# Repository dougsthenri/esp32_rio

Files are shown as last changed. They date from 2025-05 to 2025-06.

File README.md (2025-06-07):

# ESP32 Remote I/O

A low-cost industrial remote input/output device based on the ESP32-S3 SoC from Espressif.

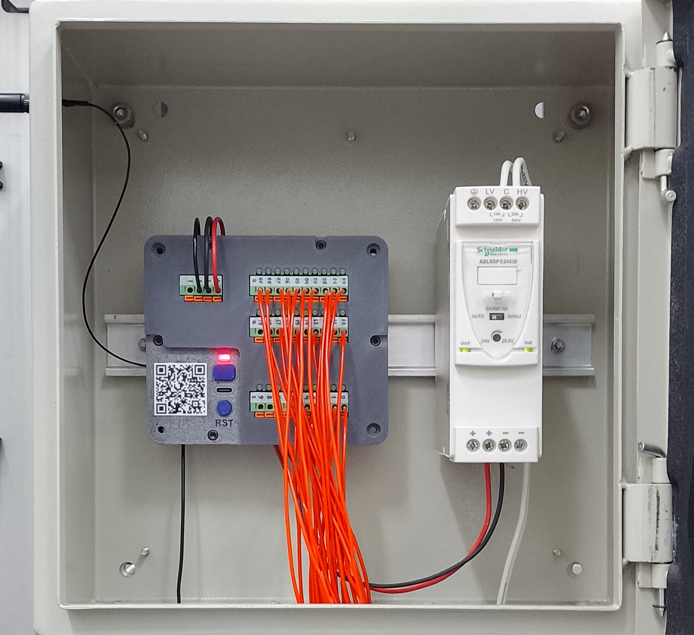
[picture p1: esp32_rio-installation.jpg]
ESP32 RIO installation ESP32 RIO installed inside panel


## Features

* **WiFi Connectivity:** Connects to an existing WiFi network using configuration read from non-volatile storage. External antenna.
* **Digital Inputs (DI):** Ten 24 V digital, sink type, inputs.
* **Digital Outputs (DQ):** Twenty 24 V digital, sink type, outputs.
* **Output Enable (OE) Button:** A push button to globally enable/disable digital outputs.
* **Status LED:** Steady on when digital outputs are enabled. Blinks Morse code for the letter W when disconnected from WiFi network.
* **USB Console:** A command-line interface over USB Serial/JTAG for runtime configuration (e.g., WiFi setup) and debugging.
* **Reset Button:** For manually restarting the board.
* **Power Input:** 24 V, 267 mA (max.).

---
*For any issues or contributions, please refer to the project's [GitHub repository](https://github.com/dougsthenri/esp32_rio.git).*

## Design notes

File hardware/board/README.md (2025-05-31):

# esp32_rio
PCB project for a low-cost industrial remote I/O device based on the ESP32-S3 SoC from Espressif.
Proudly made using KiCad 9.0.

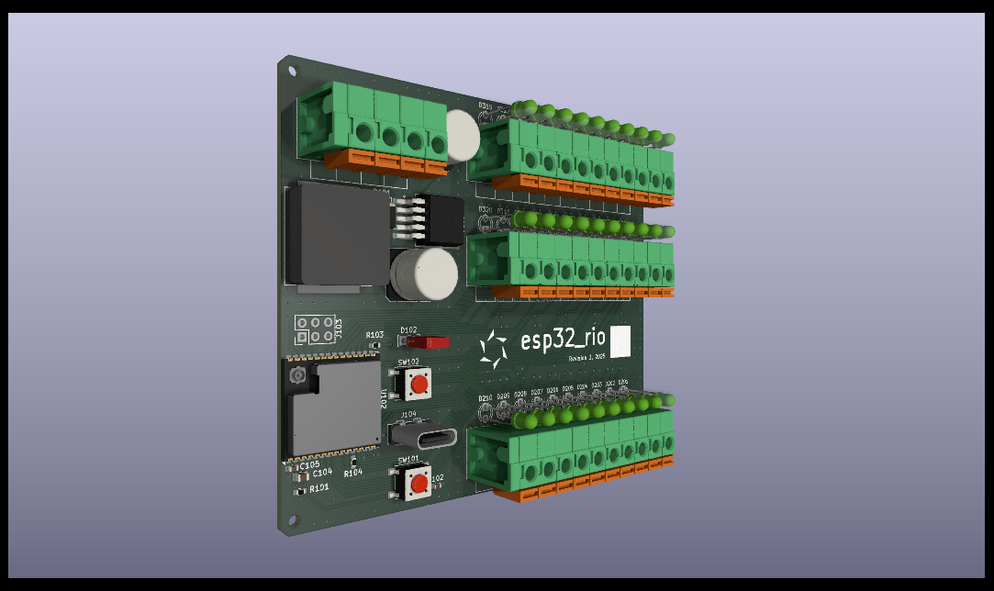
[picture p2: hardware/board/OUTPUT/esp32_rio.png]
PCB rendering


---
*For any issues or contributions, please refer to the project's [GitHub repository](https://github.com/dougsthenri/esp32_rio.git).*

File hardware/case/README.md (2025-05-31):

# ESP32 Remote I/O Case
A 3D-printable plastic case for the ESP32 RIO board.

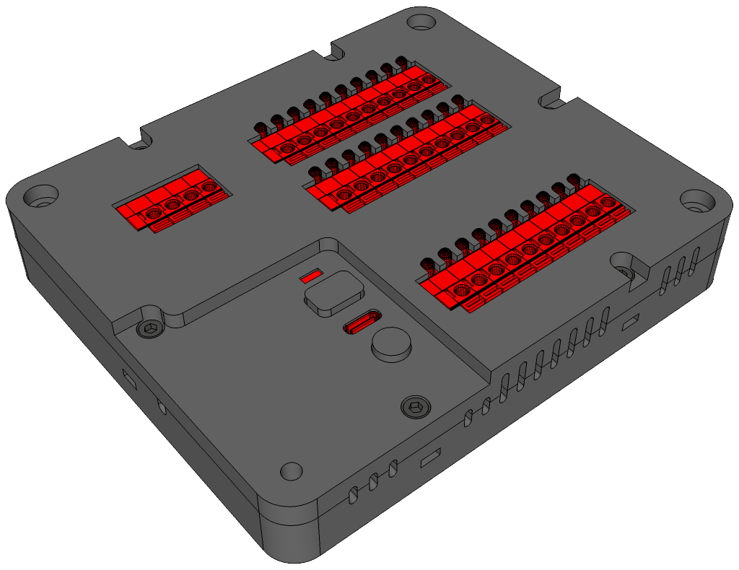
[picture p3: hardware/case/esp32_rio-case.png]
ESP32 RIO case ESP32 RIO case render


The encased board can be mounted on a 35 mm DIN rail by attaching two 43 mm mounting brackets on its back. Alternatively it can be directly mounted to a wall by using four 4x25 mm screws.
Refer to the `esp32_rio-case.skp` file for the complete case assembly.

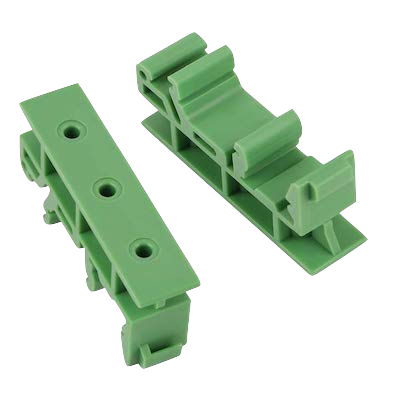
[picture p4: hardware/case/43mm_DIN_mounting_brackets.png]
43 mm DIN mounting brackets


---
*For any issues or contributions, please refer to the project's [GitHub repository](https://github.com/dougsthenri/esp32_rio.git).*

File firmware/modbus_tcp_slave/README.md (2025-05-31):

# ESP32 Remote I/O Modbus TCP Slave

## Project Overview

This project implements a Modbus TCP slave firmware for the ESP32 RIO board. The board's digital inputs (DI0-9) are exposed as Modbus discrete inputs and its digital outputs (DQ00-19) as Modbus coils. The output enable function is also controllable by means of a Modbus coil.

## 1. Setup, Compile, and Flash Instructions (ESP-IDF)

This project is built using the Espressif IoT Development Framework (ESP-IDF), version 5.4.1. Follow these steps to set up your development environment, compile the firmware, and flash it onto the ESP32 RIO board.

### 1.1. Prerequisites

* **ESP-IDF Installation:** If you haven't already, follow the official ESP-IDF Getting Started Guide for your operating system. This guide will walk you through installing the necessary tools, including Python, Git, and the ESP-IDF toolchain.
    * [ESP-IDF Get Started Guide](https://docs.espressif.com/projects/esp-idf/en/latest/esp32s3/get-started/index.html)
* **Python:** Ensure Python 3.7 or higher is installed.
* **Git:** Ensure Git is installed for cloning the repository.

### 1.2. Getting the Code

1.  **Clone the repository:**
    ```bash
    git clone [https://github.com/dougsthenri/esp32_rio.git](https://github.com/dougsthenri/esp32_rio.git)
    cd esp32_rio/firmware/modbus_tcp_slave
    ```

### 1.3. Environment Setup

Before building, you need to set up the ESP-IDF environment variables. If you followed the official guide, you should have a script to do this.

* **Linux/macOS:**
    ```bash
    . $HOME/esp/esp-idf/export.sh
    ```
    (Adjust path if your ESP-IDF installation is in a different location).
* **Windows (ESP-IDF Command Prompt):** Use the `ESP-IDF Command Prompt` shortcut installed by the ESP-IDF installer.

### 1.4. Configuration

1.  **Open the project configuration menu:**
    ```bash
    idf.py menuconfig
    ```
2.  **Navigate and configure:** Make any adjustments you deem necessary to the provided configuration.
3.  **Save and exit.**

### 1.5. Build the Project

1.  **Build the application:**
    ```bash
    idf.py build
    ```
    This command will compile all source files and generate the necessary firmware binaries.

### 1.6. Flash the Firmware

1.  **Connect the ESP32 RIO board:** Connect the ESP32 RIO board to your computer via the USB-C port (USB Serial/JTAG).
2.  **Flash the firmware:**
    ```bash
    idf.py -p YOUR_SERIAL_PORT flash
    ```
    Replace `YOUR_SERIAL_PORT` with the actual serial port of the board (e.g., `/dev/ttyUSB0` on Linux, `COMx` on Windows).
    This command will erase the flash and write the new firmware.

### 1.7. Monitor Serial Output

After flashing, you can monitor the serial output for logs and debugging information:
```bash
idf.py -p YOUR_SERIAL_PORT monitor
```
Press `Ctrl+]` to exit the monitor.

## 2. Modbus Objects

The firmware implements various Modbus objects (coils, discrete inputs) that map directly to the ESP32 RIO board's GPIOs and internal functionalities. The Modbus TCP port is **502**. The Modbus slave address is **1**.

### 2.1. Modbus Register Map

| Modbus Type | Address Range | Assignment / Description |
| :--- | :--- | :--- |
| **Coils** | `0x0000` | `DQ00` (Digital Output 0) |
| | `0x0001` | `DQ01` (Digital Output 1) |
| | ... | ... |
| | `0x0009` | `DQ09` (Digital Output 9) |
| | `0x0010` (`16`) | `DQ10` (Digital Output 10) |
| | ... | ... |
| | `0x0019` (`25`) | `DQ19` (Digital Output 19) |
| | `0x001F` (`31`) | `Output Enable (OE)`: Controls the global enable/disable state for all digital outputs. `1` = enabled, `0` = disabled. This coil also reflects the state set by the physical OE toggle button. |
| **Discrete Inputs** | `0x0000` | `DI0` (Digital Input 0) |
| | `0x0001` | `DI1` (Digital Input 1) |
| | ... | ... |
| | `0x0009` | `DI9` (Digital Input 9) |

*Note: Holding Registers and Input Registers are currently not implemented in this version.*

## 3. USB Console Communication

You can interact with the board using a standard serial terminal application connected to the USB-C port. This provides a command-line interface for configuring and monitoring the Modbus slave operation.

### 3.1. How to Connect

1.  **Connect USB-C:** Plug the ESP32 RIO board into your computer using the USB-C cable.
2.  **Identify Serial Port:** The board will enumerate as a serial port. Identify its name (e.g., `/dev/ttyUSB0` on Linux, `COMx` on Windows, `/dev/cu.usbserial-xxxx` on macOS).
3.  **Open Terminal:** Use any raw serial terminal application (e.g., Arduino serial monitor, PuTTY, Termite, picocom or even `idf.py monitor`). Enable the terminal's local echo to see the commands you typed. There's no firmware support for line editing.
4.  **Configure Serial Settings:**
    * **Baud Rate:** Not strictly applicable for USB Serial, but many terminals will default to 115200. Setting it to a common speed like 115200 or 9600 usually works, as the communication is USB-native, not UART.
    * **Data Bits:** 8
    * **Stop Bits:** 1
    * **Parity:** None
    * **Flow Control:** None
5.  **Start Session:** Open the connection. You may see some log messages.

### 3.2. Console Commands

Once connected to the USB console, you can type commands and press Enter to execute them. There must be no space before or after the full command text and only a single space before each command argument. Enclose with double quotes (“) any text argument containing spaces. Double quotes and literal backslashes (\\) must be preceded by backslashes when inside quoted text.

| Command | Description |
| :--- | :--- |
| `help` | Displays a list of all recognized commands and their brief descriptions. |
| `wifi-status` | Shows the current WiFi connection status of the TCP Modbus slave. If connected, it will display the SSID, IP address, and other relevant network information. |
| `wifi-config SSID PASSWORD` | Configures the WiFi network credentials (SSID and password) for the TCP Modbus slave to connect to. Both arguments are mandatory and non-empty. After a successful configuration, the device will save the credentials to NVS and reboot to connect. |

**Example Usage:**

```
wifi-config "My Wifi Network" MySecurePassword
[wifi-config] Configuration successful. Rebooting...
```
```
wifi-status
[wifi-status] Connected to "My Wifi Network":
  IP Address: 192.168.1.100
  Subnet Mask: 255.255.255.0
  Gateway: 192.168.1.1
```

---
*For any issues or contributions, please refer to the project's [GitHub repository](https://github.com/dougsthenri/esp32_rio.git).*

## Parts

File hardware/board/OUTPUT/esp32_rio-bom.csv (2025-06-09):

Reference | Value | Qty | DNP | Part# | Tolerance | Voltage
C101 | 100µ | 1 |  | EEHZC1H101P |  | 50V
C102 | 1µ | 1 |  | CL10B105KQ8NNNC |  | 6.3V
C103 | 680µ | 1 |  | EEEFK1V331P |  | 35V
C104 | 22µ | 1 |  | GRM21BZ70J226ME44L |  | 6.3V
C105,C201,C202,C203,C204,C205 | 100n | 6 |  | CC0603JRX7R9BB104
C206 | 10µ | 1 |  | CL21B106KAYQNNE
D101 | SS26T3G | 1 |  | SS26T3G
D102 | Red | 1 |  | L-403SRD
D201,D202,D203,D204,D205,D206,D207,D208,D209,D210,D301,D302,D303,D304,D305,D306,D307,D308,D309,D310,D311,D312,D313,D314,D315,D316,D317,D318,D319,D320 | Green | 30 |  | 204-10SYGD/S530-E2-L
J101 | 24V_Power | 1 |  | KF142V-5.08-4P
J103 | External_Programmer | 1 | DNP
J104 | Programming_Port | 1 |  | GT-USB-7035D
J201 | Digital_Input | 1 |  | KF142V-5.08-10P
J301 | Digital_Output_Bank_0 | 1 |  | KF142V-5.08-10P
J302 | Digital_Output_Bank_1 | 1 |  | KF142V-5.08-10P
L101 | 68µ | 1 |  | IHLP6767GZER680M11
Q101,Q201,Q202,Q203,Q204,Q205,Q206,Q207,Q208,Q209,Q210,Q321,Q322,Q323,Q324,Q325,Q326,Q327,Q328,Q329,Q330,Q331,Q332,Q333,Q334,Q335,Q336,Q337,Q338,Q339,Q340 | BSS138 | 31 |  | BSS138-7-F
Q301,Q302,Q303,Q304,Q305,Q306,Q307,Q308,Q309,Q310,Q311,Q312,Q313,Q314,Q315,Q316,Q317,Q318,Q319,Q320 | IRLML6344 | 20 |  | IRLML6344TRPBF
R101,R102,R103 | 10k | 3 |  | RC0603FR-0710KL
R104 | 100 | 1 |  | AC0603FR-07100RL
R105,R272,R273,R274,R275,R276,R277,R278,R279,R280,R281,R301,R302,R303,R304,R305,R306,R307,R308,R309,R310,R311,R312,R313,R314,R315,R316,R317,R318,R319,R320 | 68 | 31 |  | RC0603FR-0768RL
R106,R107 | 5.1k | 2 |  | RC0603FR-075K1L | 1%
R201,R202,R203,R204,R205,R206,R207,R208,R209,R210,R211,R212,R213,R214,R215,R216,R241,R242,R243,R244,R245,R246,R247,R248,R249,R250,R251,R252,R253,R254,R255,R256,R263,R264,R265,R267,R268,R269,R270,R271 | 1M | 40 |  | RC0603FR-071ML | 1%
R217,R218,R219,R220,R237,R238,R239,R240,R261,R262 | 649k | 10 |  | RC0603FR-07649KL | 1%
R221,R222,R223,R224,R233,R234,R235,R236,R259,R260 | 1.2k | 10 |  | RC0603FR-071K2L | 1%
R225,R226,R227,R228,R229,R230,R231,R232,R257,R258 | 10k | 10 |  | RC0603FR-0710KL | 1%
R266 | 330 | 1 |  | RC0603FR-07330RL
SW101 | Reset | 1 |  | PTS645SH95SMTR92LFS
SW102 | Toggle_Outputs | 1 |  | PTS645SH95SMTR92LFS
U101 | LM2596S-3.3 | 1 |  | LM2596SX-3.3/NOPB
U102 | ESP32-S3-WROOM-1U | 1 |  | ESP32-S3-WROOM-1U-N16R2
U201,U202,U203,U204,U205 | TLV3202AID | 5 |  | TLV3202AIDR
U206 | TL431 | 1 |  | ZTL431AFTA

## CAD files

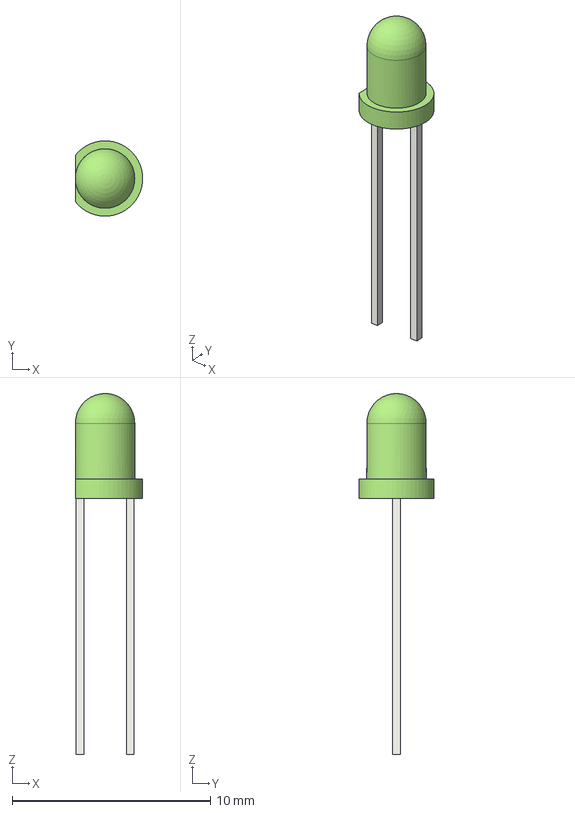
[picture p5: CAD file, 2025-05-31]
hardware/board/esp32_rio-3dmodels/LED_D3.0mm_H15.7mm_Green.step
3.40 x 3.80 x 18.2 mm
LED_Body
Cathode
Anode

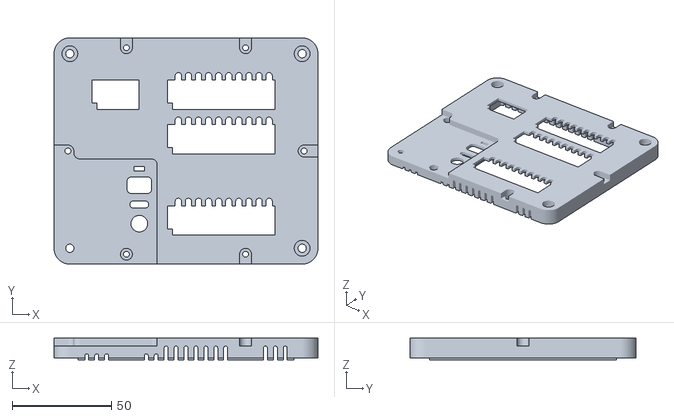
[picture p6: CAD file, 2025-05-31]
hardware/case/esp32_rio-case-top_half.stl
133.0 x 114.0 x 11.0

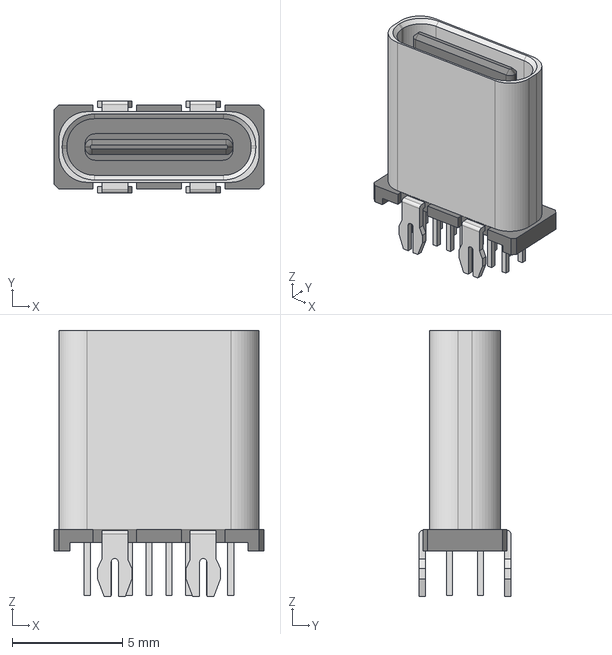
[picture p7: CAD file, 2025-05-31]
hardware/board/esp32_rio-3dmodels/CUI_UJ20-C-V-C-3-SMT-TR.stp
9.50 x 4.16 x 12.0 mm

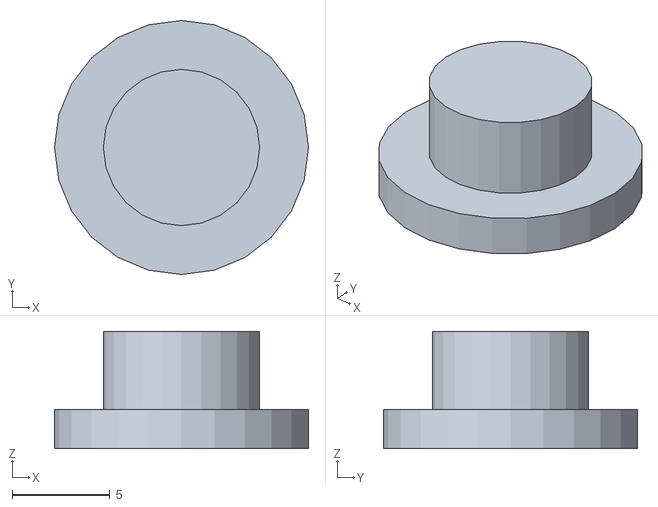
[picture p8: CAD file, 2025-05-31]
hardware/case/esp32_rio-case-reset_button.stl
13.0 x 13.0 x 6.00

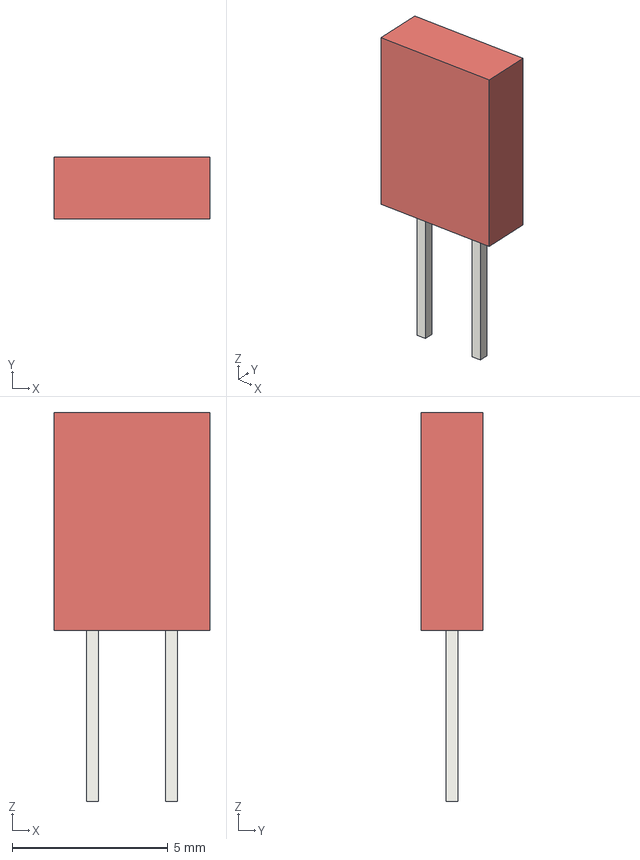
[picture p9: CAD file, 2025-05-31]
hardware/board/esp32_rio-3dmodels/LED_Rectangular_W5.0mm_H2.0mm_L10mm_Red.step
5.00 x 2.00 x 12.5 mm

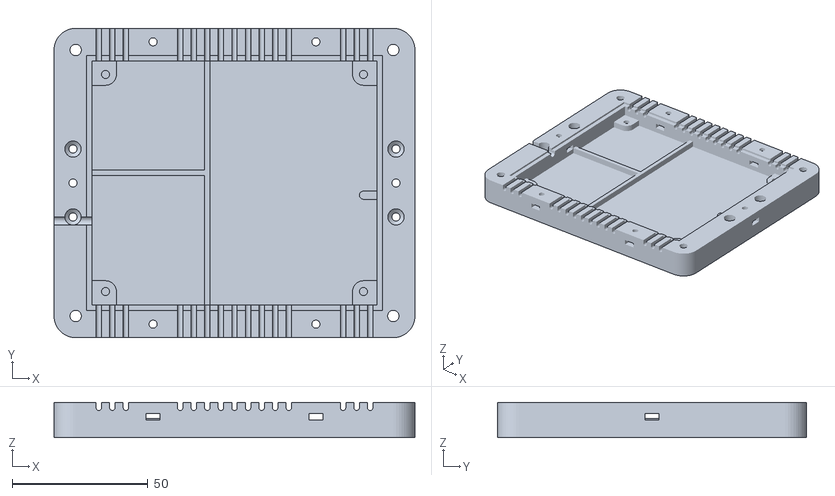
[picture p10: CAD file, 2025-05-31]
hardware/case/esp32_rio-case-bottom_half.stl
133.0 x 114.0 x 13.0

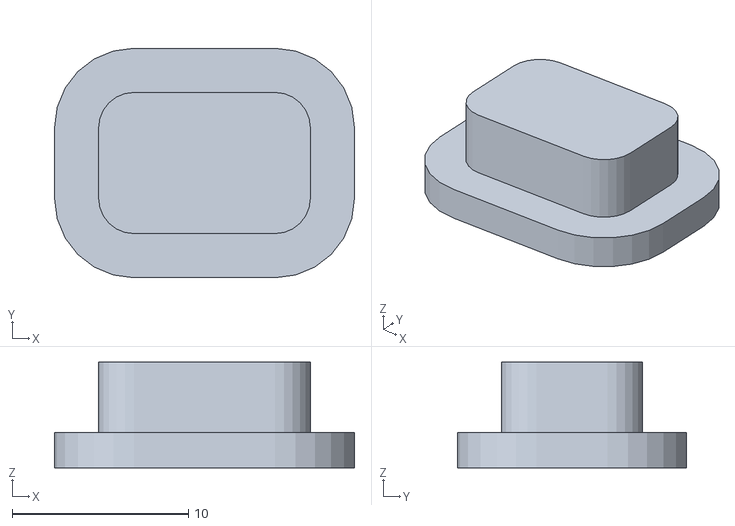
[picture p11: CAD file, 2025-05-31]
hardware/case/esp32_rio-case-oe_button.stl
17.0 x 13.0 x 6.00

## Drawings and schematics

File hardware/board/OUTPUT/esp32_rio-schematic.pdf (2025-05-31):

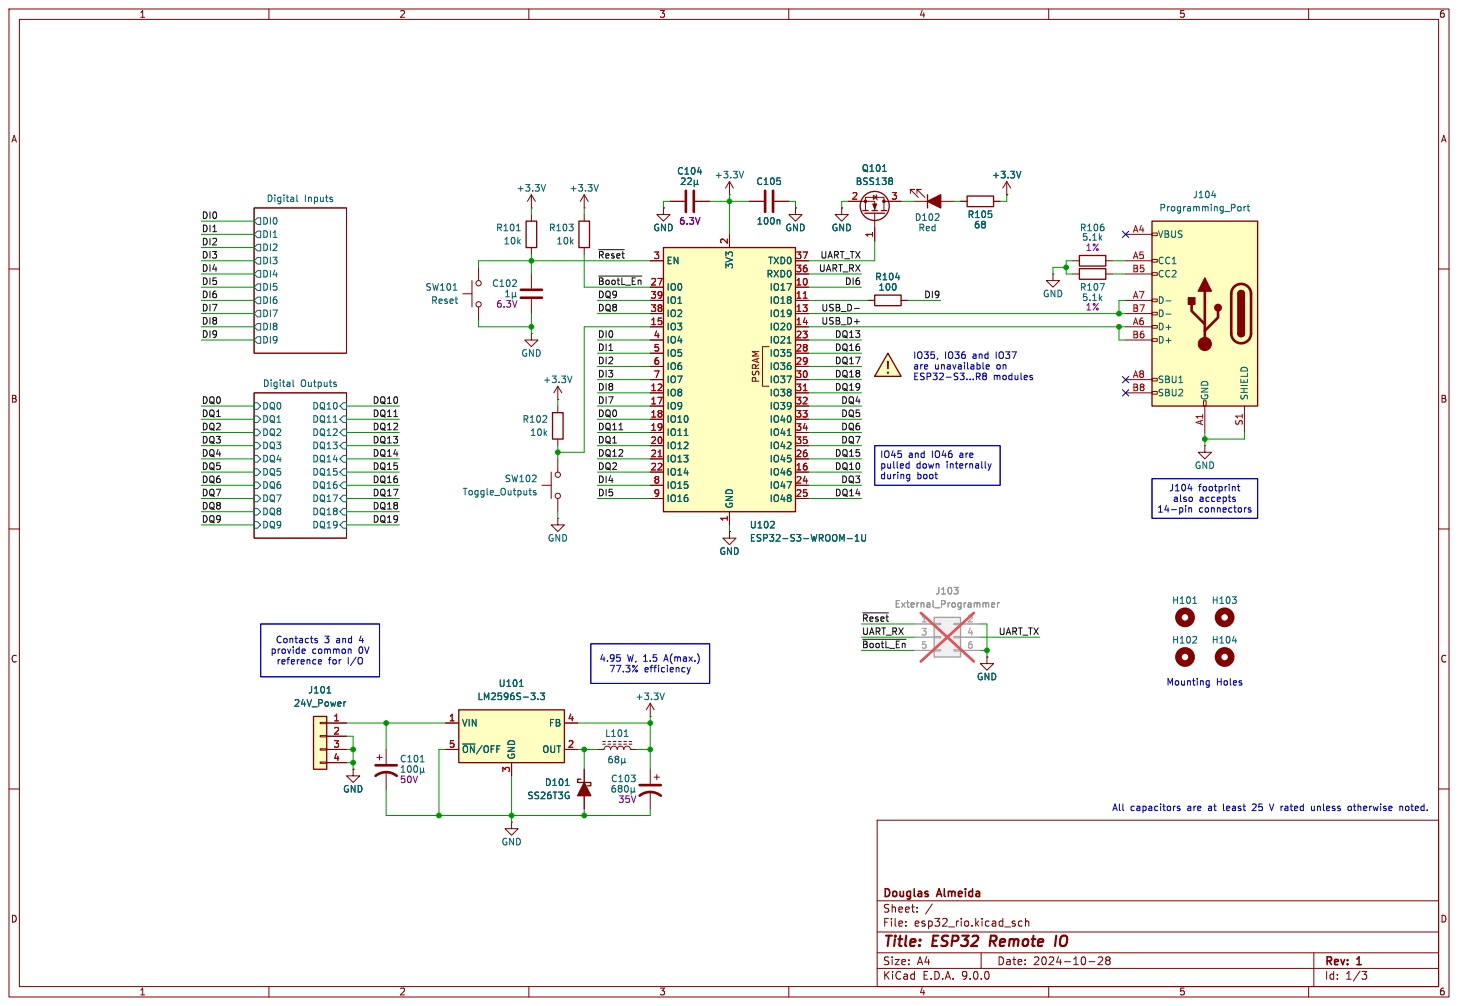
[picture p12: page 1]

File: esp32_rio.kicad_sch Sheet: / Douglas Almeida

Id: 1/3 Title: ESP32 Remote IO

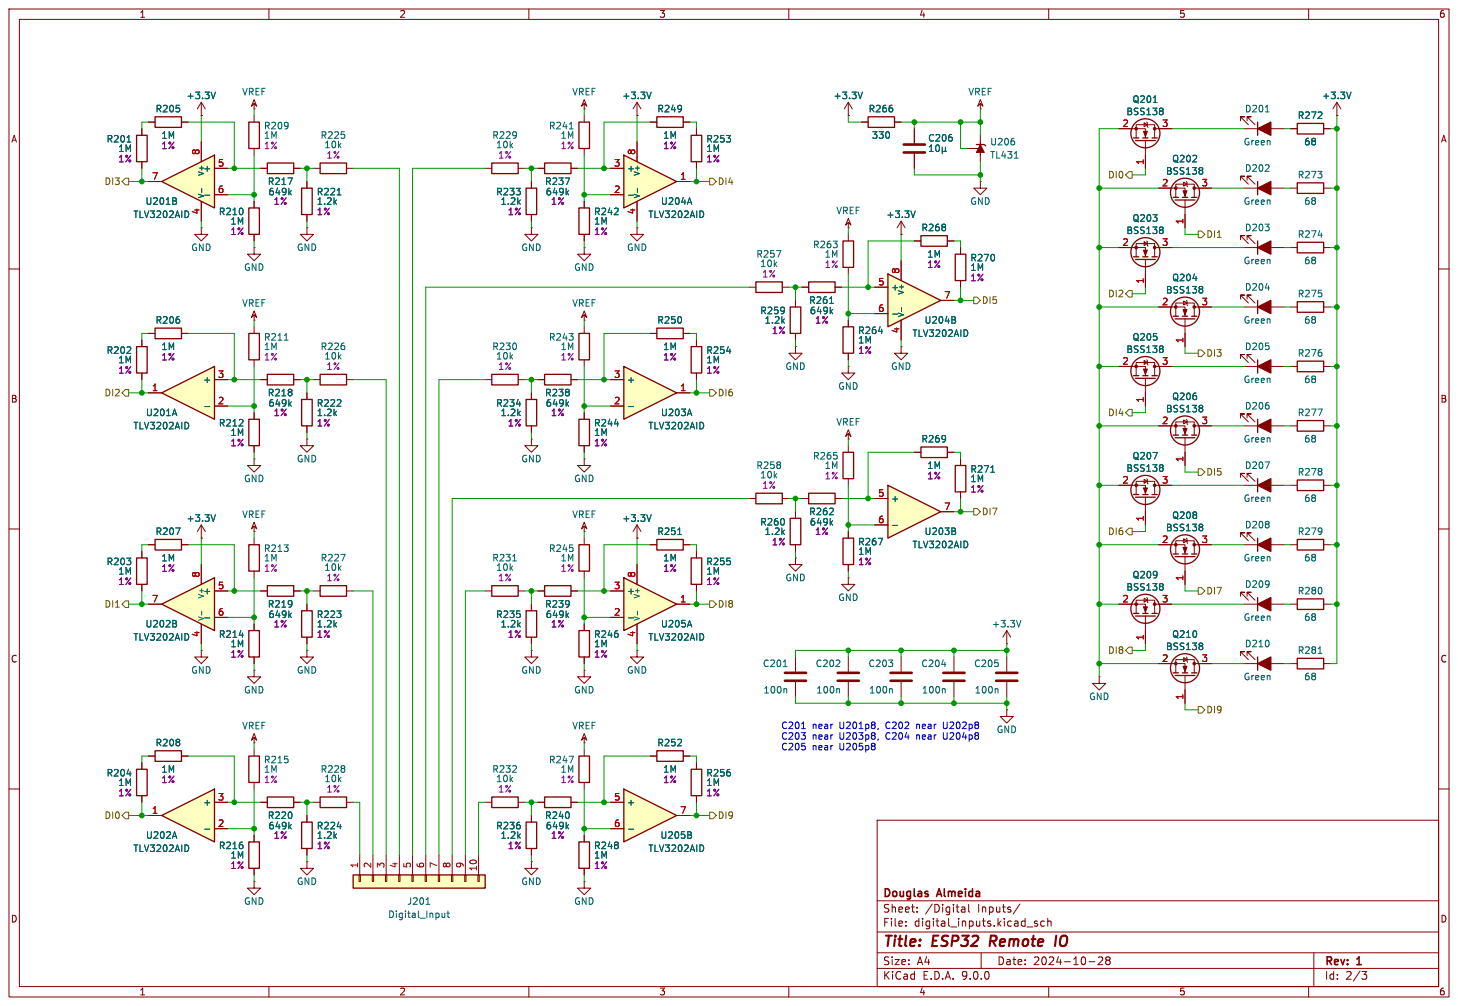
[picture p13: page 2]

Id: 2/3 Title: ESP32 Remote IO

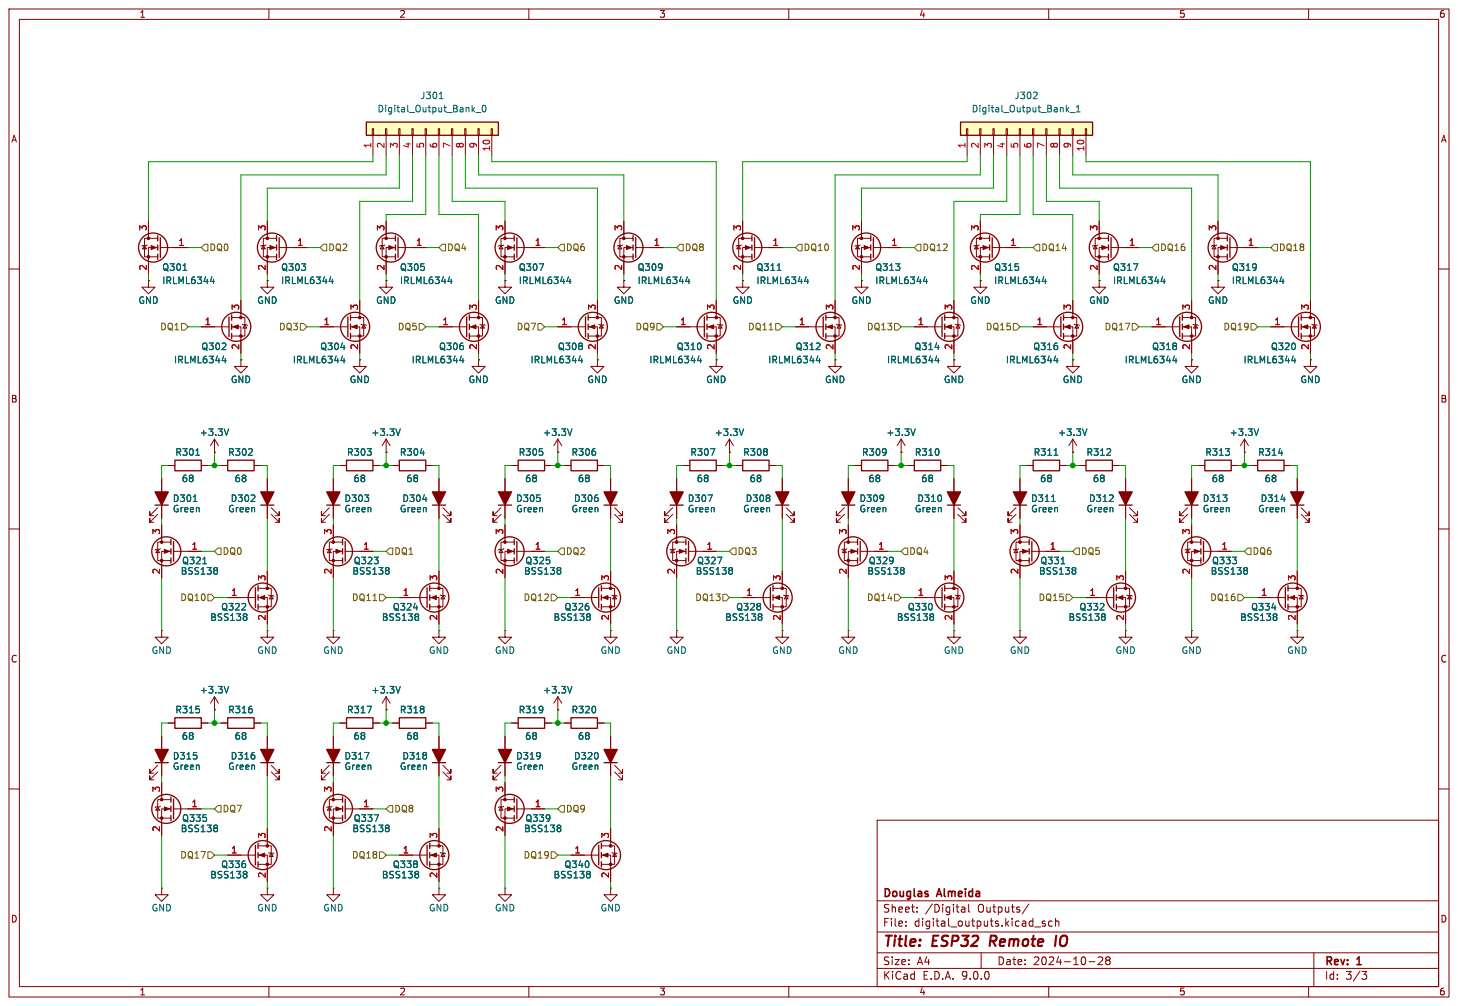
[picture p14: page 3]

Douglas Almeida
Id: 3/3 Title: ESP32 Remote IO

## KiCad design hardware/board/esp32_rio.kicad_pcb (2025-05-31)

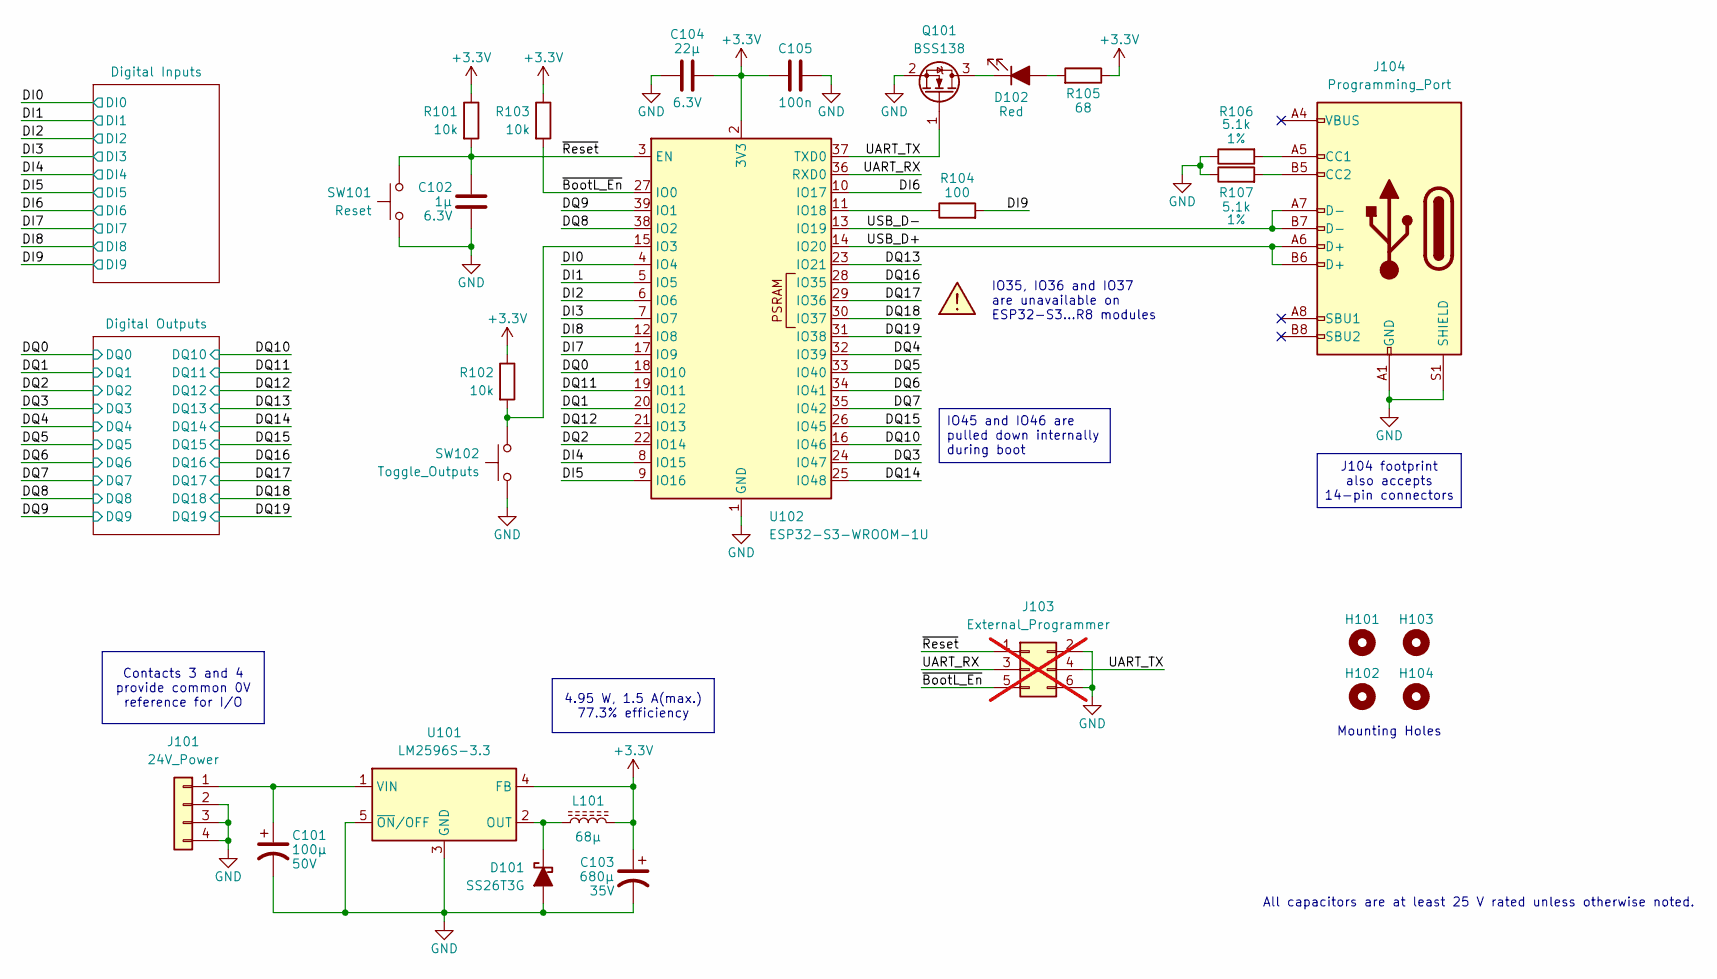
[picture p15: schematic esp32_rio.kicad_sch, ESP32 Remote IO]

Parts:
C101: 100µ; C_Elec_10x10.2; Voltage 50V; Part# EEHZC1H101P
C102: 1µ; C_0603_1608Metric; Voltage 6.3V; Part# CL10B105KQ8NNNC
C103: 680µ; C_Elec_10x10.2; Voltage 35V; Part# EEEFK1V331P
C104: 22µ; C_0805_2012Metric; Voltage 6.3V; Part# GRM21BZ70J226ME44L
C105: 100n; C_0603_1608Metric; Part# CC0603JRX7R9BB104
D101: SS26T3G; D_SMB; Part# SS26T3G
D102: Red; LED_Rectangular_W5.0mm_H2.0mm; Part# L-403SRD
H101, H102, H103, H104: MountingHole; MountingHole_2.1mm
J101: 24V_Power; Kefa_KF142V-5.08-4P; Part# KF142V-5.08-4P
J103: External_Programmer; PinHeader_2x03_P2.54mm_Vertical; not fitted
J104: Programming_Port; CUI_UJ20-C-V-C-3-SMT-TR; Part# GT-USB-7035D
L101: 68µ; L_Vishay_IHLP-6767; Part# IHLP6767GZER680M11
Q101: BSS138; SOT-23; Part# BSS138-7-F
R101, R102, R103: 10k; R_0603_1608Metric; Part# RC0603FR-0710KL
R104: 100; R_0603_1608Metric; Part# AC0603FR-07100RL
R105: 68; R_0603_1608Metric; Part# RC0603FR-0768RL
R106, R107: 5.1k; R_0603_1608Metric; Tolerance 1%; Part# RC0603FR-075K1L
SW101: Reset; SW_SPST_PTS645; Part# PTS645SH95SMTR92LFS
SW102: Toggle_Outputs; SW_SPST_PTS645; Part# PTS645SH95SMTR92LFS
U101: LM2596S-3.3; TO-263-5_TabPin3; Part# LM2596SX-3.3/NOPB
U102: ESP32-S3-WROOM-1U; Part# ESP32-S3-WROOM-1U-N16R2

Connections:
+3.3V: C103.1, C104.1, C105.2, L101.2, R101.1, R102.1, R103.1, R105.1, U101.4 (FB), U102.2 (3V3); also elsewhere on the board
/DI0: U102.4 (IO4); also elsewhere on the board
/DI1: U102.5 (IO5); also elsewhere on the board
/DI2: U102.6 (IO6); also elsewhere on the board
/DI3: U102.7 (IO7); also elsewhere on the board
/DI4: U102.8 (IO15); also elsewhere on the board
/DI5: U102.9 (IO16); also elsewhere on the board
/DI6: U102.10 (IO17); also elsewhere on the board
/DI7: U102.17 (IO9); also elsewhere on the board
/DI8: U102.12 (IO8); also elsewhere on the board
/DI9: R104.2; also elsewhere on the board
/DQ0: U102.18 (IO10); also elsewhere on the board
/DQ1: U102.20 (IO12); also elsewhere on the board
/DQ2: U102.22 (IO14); also elsewhere on the board
/DQ3: U102.24 (IO47); also elsewhere on the board
/DQ4: U102.32 (IO39); also elsewhere on the board
/DQ5: U102.33 (IO40); also elsewhere on the board
/DQ6: U102.34 (IO41); also elsewhere on the board
/DQ7: U102.35 (IO42); also elsewhere on the board
/DQ8: U102.38 (IO2); also elsewhere on the board
/DQ9: U102.39 (IO1); also elsewhere on the board
/DQ10: U102.16 (IO46); also elsewhere on the board
/DQ11: U102.19 (IO11); also elsewhere on the board
/DQ12: U102.21 (IO13); also elsewhere on the board
/DQ13: U102.23 (IO21); also elsewhere on the board
/DQ14: U102.25 (IO48); also elsewhere on the board
/DQ15: U102.26 (IO45); also elsewhere on the board
/DQ16: U102.28 (IO35); also elsewhere on the board
/DQ17: U102.29 (IO36); also elsewhere on the board
/DQ18: U102.30 (IO37); also elsewhere on the board
/DQ19: U102.31 (IO38); also elsewhere on the board
/UART_RX: J103.3, U102.36 (RXD0)
/UART_TX: J103.4, Q101.1 (G), U102.37 (TXD0)
/USB_D+: J104.A6 (D+), J104.B6 (D+), U102.14 (IO20)
/USB_D-: J104.A7 (D-), J104.B7 (D-), U102.13 (IO19)
/~BootL_En: J103.5, R103.2, U102.27 (IO0)
/~Reset: C102.1, J103.1, R101.2, SW101.2, U102.3 (EN)
GND: C101.2, C102.2, C103.2, C104.2, C105.1, D101.2 (A), J101.2, J101.3, J101.4, J103.2, J103.6, J104.A1 (GND), J104.A12 (GND), J104.B1 (GND), J104.B12 (GND), J104.S1 (SHIELD), Q101.2 (S), R106.1, R107.1, SW101.1, SW102.1, U101.3 (GND), U101.5 (~ON/OFF), U102.1 (GND), U102.40 (GND), U102.41 (GND); also elsewhere on the board
unnamed: D101.1 (K), L101.1, U101.2 (OUT)
unnamed: D102.2 (A), R105.2
unnamed: D102.1 (K), Q101.3 (D)
unnamed: C101.1, J101.1, U101.1 (VIN)
unnamed: J104.A5 (CC1), R106.2
unnamed: J104.B5 (CC2), R107.2
unnamed: R102.2, SW102.2, U102.15 (IO3)
unnamed: R104.1, U102.11 (IO18)

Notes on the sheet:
Mounting Holes
All capacitors are at least 25 V rated unless otherwise noted.
J104 footprint also accepts 14-pin connectors
4.95 W, 1.5 A(max.) 77.3% efficiency
IO35, IO36 and IO37 are unavailable on ESP32-S3...R8 modules
Contacts 3 and 4 provide common 0V reference for I/O
IO45 and IO46 are pulled down internally during boot

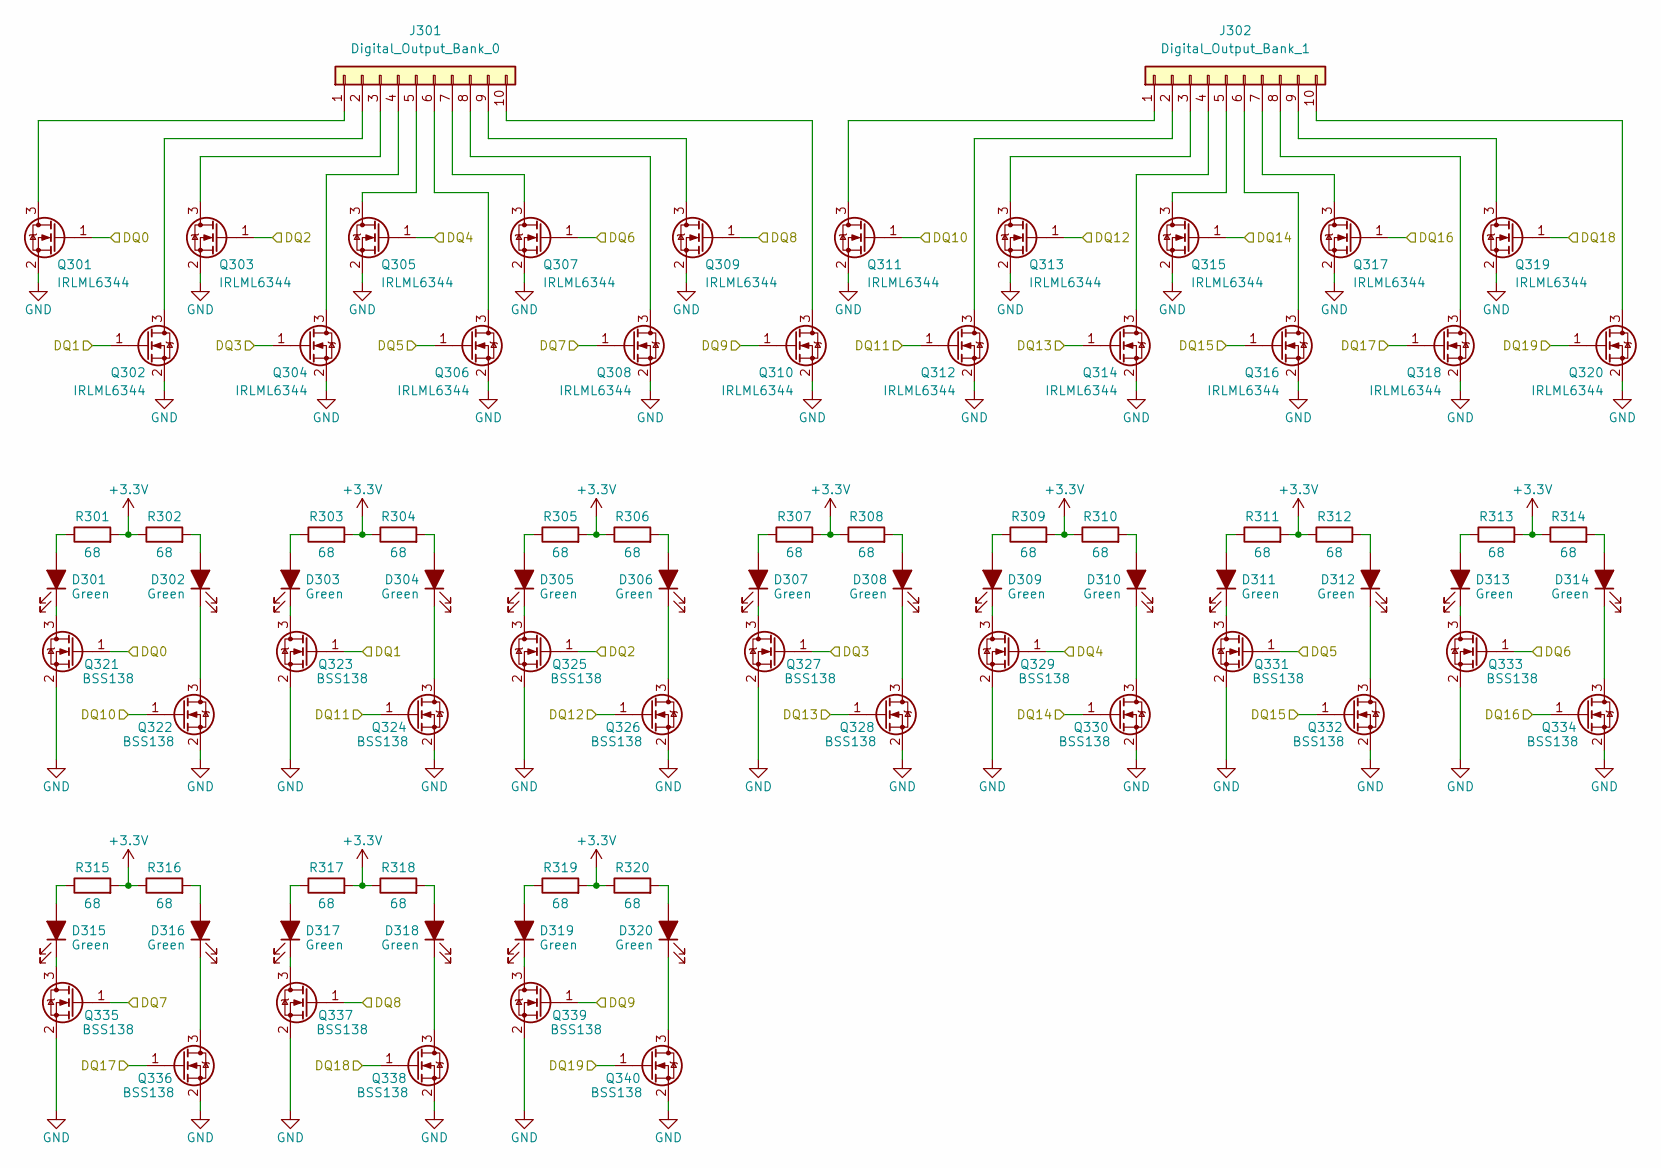
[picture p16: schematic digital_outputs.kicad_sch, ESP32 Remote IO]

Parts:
D301, D302, D303, D304, D305, D306, D307, D308, D309, D310, D311, D312, D313, D314, D315, D316, D317, D318, D319, D320: Green; LED_D3.0mm; Part# 204-10SYGD/S530-E2-L
J301: Digital_Output_Bank_0; Kefa_KF142V-5.08-10P; Part# KF142V-5.08-10P
J302: Digital_Output_Bank_1; Kefa_KF142V-5.08-10P; Part# KF142V-5.08-10P
Q301, Q302, Q303, Q304, Q305, Q306, Q307, Q308, Q309, Q310, Q311, Q312, Q313, Q314, Q315, Q316, Q317, Q318, Q319, Q320: IRLML6344; SOT-23; Part# IRLML6344TRPBF
Q321, Q322, Q323, Q324, Q325, Q326, Q327, Q328, Q329, Q330, Q331, Q332, Q333, Q334, Q335, Q336, Q337, Q338, Q339, Q340: BSS138; SOT-23; Part# BSS138-7-F
R301, R302, R303, R304, R305, R306, R307, R308, R309, R310, R311, R312, R313, R314, R315, R316, R317, R318, R319, R320: 68; R_0603_1608Metric; Part# RC0603FR-0768RL

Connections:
+3.3V: R301.2, R302.1, R303.2, R304.1, R305.2, R306.1, R307.2, R308.1, R309.2, R310.1, R311.2, R312.1, R313.2, R314.1, R315.2, R316.1, R317.2, R318.1, R319.2, R320.1; also elsewhere on the board
/DQ0: Q301.1 (G), Q321.1 (G); also elsewhere on the board
/DQ1: Q302.1 (G), Q323.1 (G); also elsewhere on the board
/DQ2: Q303.1 (G), Q325.1 (G); also elsewhere on the board
/DQ3: Q304.1 (G), Q327.1 (G); also elsewhere on the board
/DQ4: Q305.1 (G), Q329.1 (G); also elsewhere on the board
/DQ5: Q306.1 (G), Q331.1 (G); also elsewhere on the board
/DQ6: Q307.1 (G), Q333.1 (G); also elsewhere on the board
/DQ7: Q308.1 (G), Q335.1 (G); also elsewhere on the board
/DQ8: Q309.1 (G), Q337.1 (G); also elsewhere on the board
/DQ9: Q310.1 (G), Q339.1 (G); also elsewhere on the board
/DQ10: Q311.1 (G), Q322.1 (G); also elsewhere on the board
/DQ11: Q312.1 (G), Q324.1 (G); also elsewhere on the board
/DQ12: Q313.1 (G), Q326.1 (G); also elsewhere on the board
/DQ13: Q314.1 (G), Q328.1 (G); also elsewhere on the board
/DQ14: Q315.1 (G), Q330.1 (G); also elsewhere on the board
/DQ15: Q316.1 (G), Q332.1 (G); also elsewhere on the board
/DQ16: Q317.1 (G), Q334.1 (G); also elsewhere on the board
/DQ17: Q318.1 (G), Q336.1 (G); also elsewhere on the board
/DQ18: Q319.1 (G), Q338.1 (G); also elsewhere on the board
/DQ19: Q320.1 (G), Q340.1 (G); also elsewhere on the board
GND: Q301.2 (S), Q302.2 (S), Q303.2 (S), Q304.2 (S), Q305.2 (S), Q306.2 (S), Q307.2 (S), Q308.2 (S), Q309.2 (S), Q310.2 (S), Q311.2 (S), Q312.2 (S), Q313.2 (S), Q314.2 (S), Q315.2 (S), Q316.2 (S), Q317.2 (S), Q318.2 (S), Q319.2 (S), Q320.2 (S), Q321.2 (S), Q322.2 (S), Q323.2 (S), Q324.2 (S), Q325.2 (S), Q326.2 (S), Q327.2 (S), Q328.2 (S), Q329.2 (S), Q330.2 (S), Q331.2 (S), Q332.2 (S), Q333.2 (S), Q334.2 (S), Q335.2 (S), Q336.2 (S), Q337.2 (S), Q338.2 (S), Q339.2 (S), Q340.2 (S); also elsewhere on the board
unnamed: D301.2 (A), R301.1
unnamed: D301.1 (K), Q321.3 (D)
unnamed: D302.2 (A), R302.2
unnamed: D302.1 (K), Q322.3 (D)
unnamed: D303.2 (A), R303.1
unnamed: D303.1 (K), Q323.3 (D)
unnamed: D304.2 (A), R304.2
unnamed: D304.1 (K), Q324.3 (D)
unnamed: D305.2 (A), R305.1
unnamed: D305.1 (K), Q325.3 (D)
unnamed: D306.2 (A), R306.2
unnamed: D306.1 (K), Q326.3 (D)
unnamed: D307.2 (A), R307.1
unnamed: D307.1 (K), Q327.3 (D)
unnamed: D308.2 (A), R308.2
unnamed: D308.1 (K), Q328.3 (D)
unnamed: D309.2 (A), R309.1
unnamed: D309.1 (K), Q329.3 (D)
unnamed: D310.2 (A), R310.2
unnamed: D310.1 (K), Q330.3 (D)
unnamed: D311.2 (A), R311.1
unnamed: D311.1 (K), Q331.3 (D)
unnamed: D312.2 (A), R312.2
unnamed: D312.1 (K), Q332.3 (D)
unnamed: D313.2 (A), R313.1
unnamed: D313.1 (K), Q333.3 (D)
unnamed: D314.2 (A), R314.2
unnamed: D314.1 (K), Q334.3 (D)
unnamed: D315.2 (A), R315.1
unnamed: D315.1 (K), Q335.3 (D)
unnamed: D316.2 (A), R316.2
unnamed: D316.1 (K), Q336.3 (D)
unnamed: D317.2 (A), R317.1
unnamed: D317.1 (K), Q337.3 (D)
unnamed: D318.2 (A), R318.2
unnamed: D318.1 (K), Q338.3 (D)
unnamed: D319.2 (A), R319.1
unnamed: D319.1 (K), Q339.3 (D)
unnamed: D320.2 (A), R320.2
unnamed: D320.1 (K), Q340.3 (D)
unnamed: J301.1, Q301.3 (D)
unnamed: J301.2, Q302.3 (D)
unnamed: J301.3, Q303.3 (D)
unnamed: J301.4, Q304.3 (D)
unnamed: J301.5, Q305.3 (D)
unnamed: J301.6, Q306.3 (D)
unnamed: J301.7, Q307.3 (D)
unnamed: J301.8, Q308.3 (D)
unnamed: J301.9, Q309.3 (D)
unnamed: J301.10, Q310.3 (D)
unnamed: J302.1, Q311.3 (D)
unnamed: J302.2, Q312.3 (D)
unnamed: J302.3, Q313.3 (D)
unnamed: J302.4, Q314.3 (D)
unnamed: J302.5, Q315.3 (D)
unnamed: J302.6, Q316.3 (D)
unnamed: J302.7, Q317.3 (D)
unnamed: J302.8, Q318.3 (D)
unnamed: J302.9, Q319.3 (D)
unnamed: J302.10, Q320.3 (D)

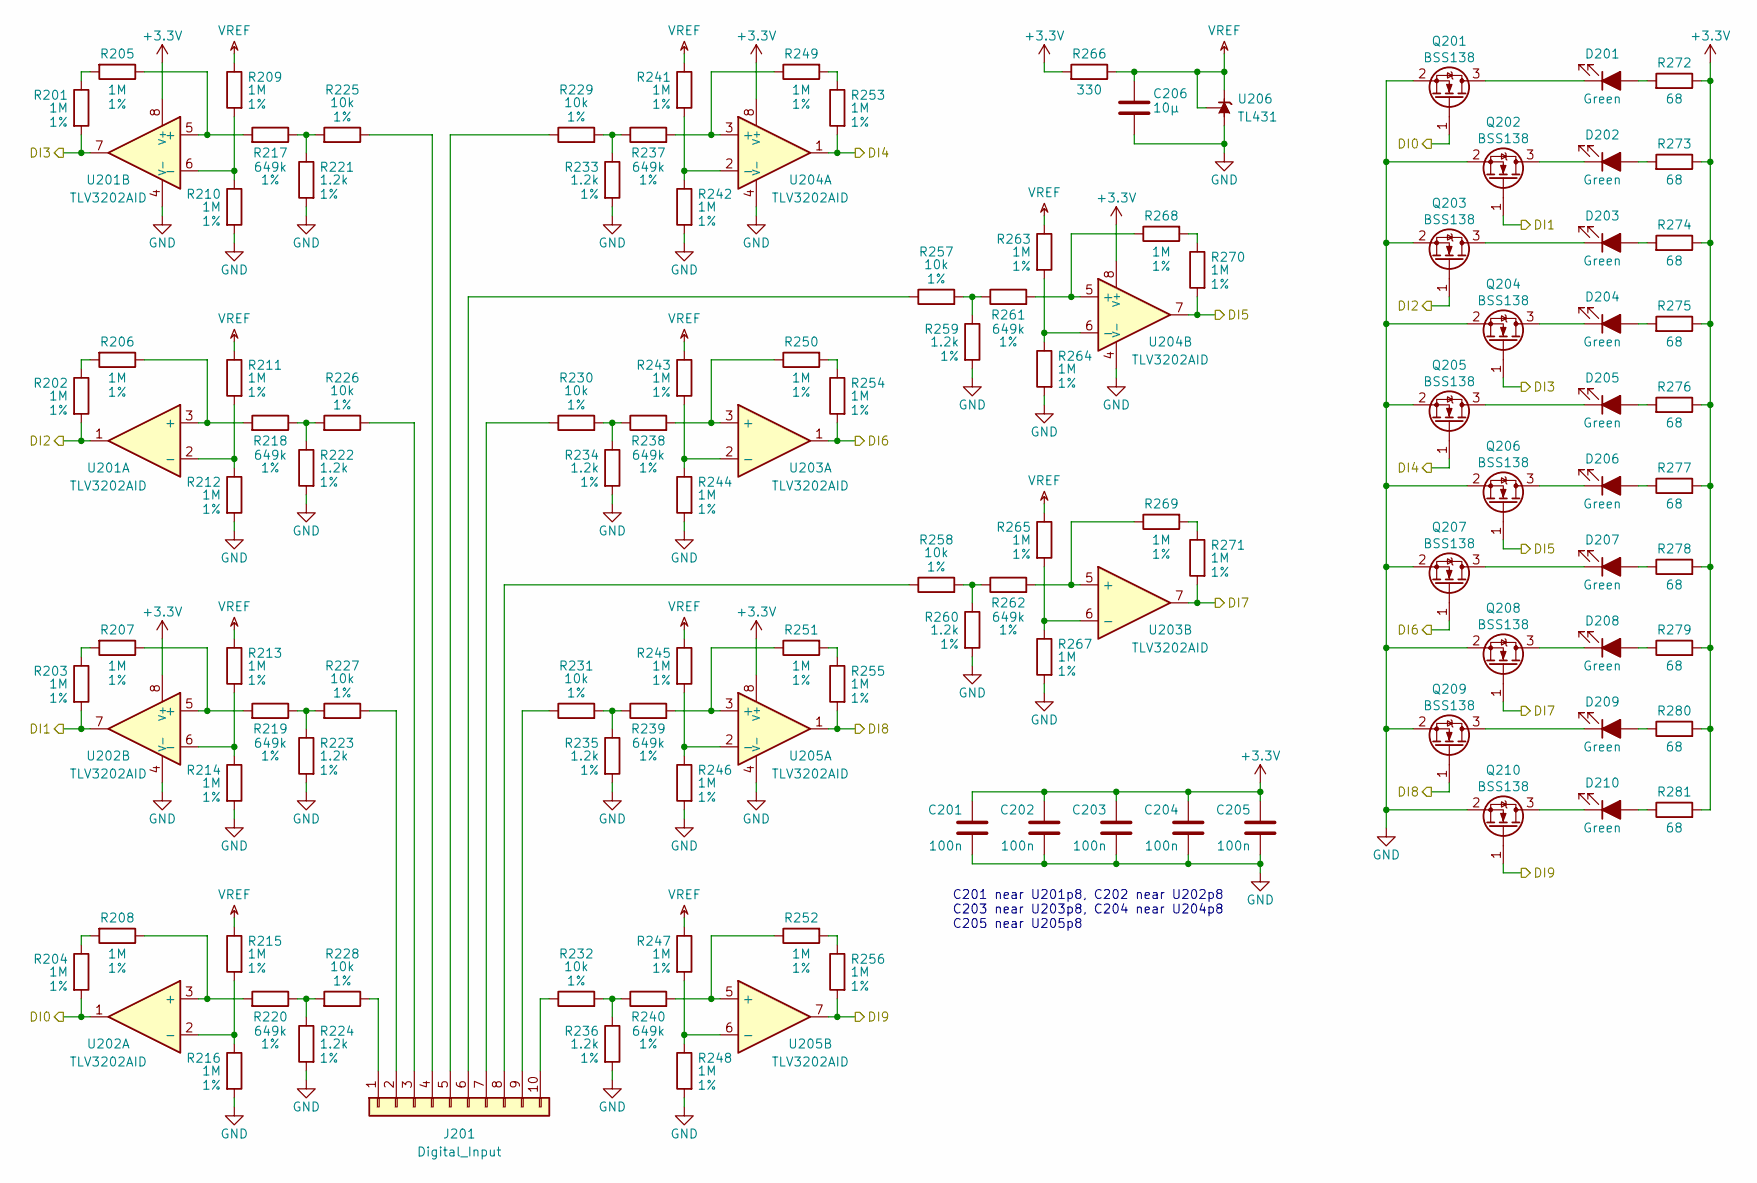
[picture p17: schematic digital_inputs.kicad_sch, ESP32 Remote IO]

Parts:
C201, C202, C203, C204, C205: 100n; C_0603_1608Metric; Part# CC0603JRX7R9BB104
C206: 10µ; C_0805_2012Metric; Part# CL21B106KAYQNNE
D201, D202, D203, D204, D205, D206, D207, D208, D209, D210: Green; LED_D3.0mm; Part# 204-10SYGD/S530-E2-L
J201: Digital_Input; Kefa_KF142V-5.08-10P; Part# KF142V-5.08-10P
Q201, Q202, Q203, Q204, Q205, Q206, Q207, Q208, Q209, Q210: BSS138; SOT-23; Part# BSS138-7-F
R201, R202, R203, R204, R205, R206, R207, R208, R209, R210, R211, R212, R213, R214, R215, R216, R241, R242, R243, R244, R245, R246, R247, R248, R249, R250, R251, R252, R253, R254, R255, R256, R263, R264, R265, R267, R268, R269, R270, R271: 1M; R_0603_1608Metric; Tolerance 1%; Part# RC0603FR-071ML
R217, R218, R219, R220, R237, R238, R239, R240, R261, R262: 649k; R_0603_1608Metric; Tolerance 1%; Part# RC0603FR-07649KL
R221, R222, R223, R224, R233, R234, R235, R236, R259, R260: 1.2k; R_0603_1608Metric; Tolerance 1%; Part# RC0603FR-071K2L
R225, R226, R227, R228, R229, R230, R231, R232, R257, R258: 10k; R_0603_1608Metric; Tolerance 1%; Part# RC0603FR-0710KL
R266: 330; R_0603_1608Metric; Part# RC0603FR-07330RL
R272, R273, R274, R275, R276, R277, R278, R279, R280, R281: 68; R_0603_1608Metric; Part# RC0603FR-0768RL
U201, U202, U203, U204, U205: TLV3202AID; SOIC-8_3.9x4.9mm_P1.27mm; Part# TLV3202AIDR
U206: TL431; SOT-23; Part# ZTL431AFTA

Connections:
+3.3V: C201.1, C202.1, C203.1, C204.1, C205.1, R266.2, R272.1, R273.1, R274.1, R275.1, R276.1, R277.2, R278.2, R279.2, R280.2, R281.2, U201.8 (V+), U202.8 (V+), U203.8 (V+), U204.8 (V+), U205.8 (V+); also elsewhere on the board
/DI0: Q201.1 (G), R204.2, U202.1; also elsewhere on the board
/DI1: Q202.1 (G), R203.2, U202.7; also elsewhere on the board
/DI2: Q203.1 (G), R202.2, U201.1; also elsewhere on the board
/DI3: Q204.1 (G), R201.2, U201.7; also elsewhere on the board
/DI4: Q205.1 (G), R253.2, U204.1; also elsewhere on the board
/DI5: Q206.1 (G), R270.2, U204.7; also elsewhere on the board
/DI6: Q207.1 (G), R254.2, U203.1; also elsewhere on the board
/DI7: Q208.1 (G), R271.2, U203.7; also elsewhere on the board
/DI8: Q209.1 (G), R255.2, U205.1; also elsewhere on the board
/DI9: Q210.1 (G), R256.2, U205.7; also elsewhere on the board
GND: C201.2, C202.2, C203.2, C204.2, C205.2, C206.2, Q201.2 (S), Q202.2 (S), Q203.2 (S), Q204.2 (S), Q205.2 (S), Q206.2 (S), Q207.2 (S), Q208.2 (S), Q209.2 (S), Q210.2 (S), R210.2, R212.2, R214.2, R216.2, R221.2, R222.2, R223.2, R224.2, R233.2, R234.2, R235.2, R236.2, R242.2, R244.2, R246.2, R248.2, R259.2, R260.2, R264.2, R267.2, U201.4 (V-), U202.4 (V-), U203.4 (V-), U204.4 (V-), U205.4 (V-), U206.3 (A); also elsewhere on the board
unnamed: D201.2 (A), R272.2
unnamed: D201.1 (K), Q201.3 (D)
unnamed: D202.2 (A), R273.2
unnamed: D202.1 (K), Q202.3 (D)
unnamed: D203.2 (A), R274.2
unnamed: D203.1 (K), Q203.3 (D)
unnamed: D204.2 (A), R275.2
unnamed: D204.1 (K), Q204.3 (D)
unnamed: D205.2 (A), R276.2
unnamed: D205.1 (K), Q205.3 (D)
unnamed: D206.2 (A), R277.1
unnamed: D206.1 (K), Q206.3 (D)
unnamed: D207.2 (A), R278.1
unnamed: D207.1 (K), Q207.3 (D)
unnamed: D208.2 (A), R279.1
unnamed: D208.1 (K), Q208.3 (D)
unnamed: D209.2 (A), R280.1
unnamed: D209.1 (K), Q209.3 (D)
unnamed: D210.2 (A), R281.1
unnamed: D210.1 (K), Q210.3 (D)
unnamed: J201.1, R228.1
unnamed: J201.2, R227.1
unnamed: J201.3, R226.1
unnamed: J201.4, R225.1
unnamed: J201.5, R229.1
unnamed: J201.6, R257.1
unnamed: J201.7, R230.1
unnamed: J201.8, R258.1
unnamed: J201.9, R231.1
unnamed: J201.10, R232.1
unnamed: R201.1, R205.2
unnamed: R202.1, R206.2
unnamed: R203.1, R207.2
unnamed: R204.1, R208.2
unnamed: R217.1, R221.1, R225.2
unnamed: R218.1, R222.1, R226.2
unnamed: R219.1, R223.1, R227.2
unnamed: R220.1, R224.1, R228.2
unnamed: R229.2, R233.1, R237.1
unnamed: R230.2, R234.1, R238.1
unnamed: R231.2, R235.1, R239.1
unnamed: R232.2, R236.1, R240.1
unnamed: R249.2, R253.1
unnamed: R250.2, R254.1
unnamed: R251.2, R255.1
unnamed: R252.2, R256.1
unnamed: R257.2, R259.1, R261.1
unnamed: R258.2, R260.1, R262.1
unnamed: R268.2, R270.1
unnamed: R269.2, R271.1
unnamed: R206.1, R218.2, U201.3 (+)
unnamed: R211.2, R212.1, U201.2 (-)
unnamed: R205.1, R217.2, U201.5 (+)
unnamed: R209.2, R210.1, U201.6 (-)
unnamed: R208.1, R220.2, U202.3 (+)
unnamed: R215.2, R216.1, U202.2 (-)
unnamed: R207.1, R219.2, U202.5 (+)
unnamed: R213.2, R214.1, U202.6 (-)
unnamed: R238.2, R250.1, U203.3 (+)
unnamed: R243.2, R244.1, U203.2 (-)
unnamed: R262.2, R269.1, U203.5 (+)
unnamed: R265.2, R267.1, U203.6 (-)
unnamed: R237.2, R249.1, U204.3 (+)
unnamed: R241.2, R242.1, U204.2 (-)
unnamed: R261.2, R268.1, U204.5 (+)
unnamed: R263.2, R264.1, U204.6 (-)
unnamed: R239.2, R251.1, U205.3 (+)
unnamed: R245.2, R246.1, U205.2 (-)
unnamed: R240.2, R252.1, U205.5 (+)
unnamed: R247.2, R248.1, U205.6 (-)
VREF: C206.1, R209.1, R211.1, R213.1, R215.1, R241.1, R243.1, R245.1, R247.1, R263.1, R265.1, R266.1, U206.1 (K), U206.2 (REF)

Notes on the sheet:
C201 near U201p8, C202 near U202p8 C203 near U203p8, C204 near U204p8 C205 near U205p8

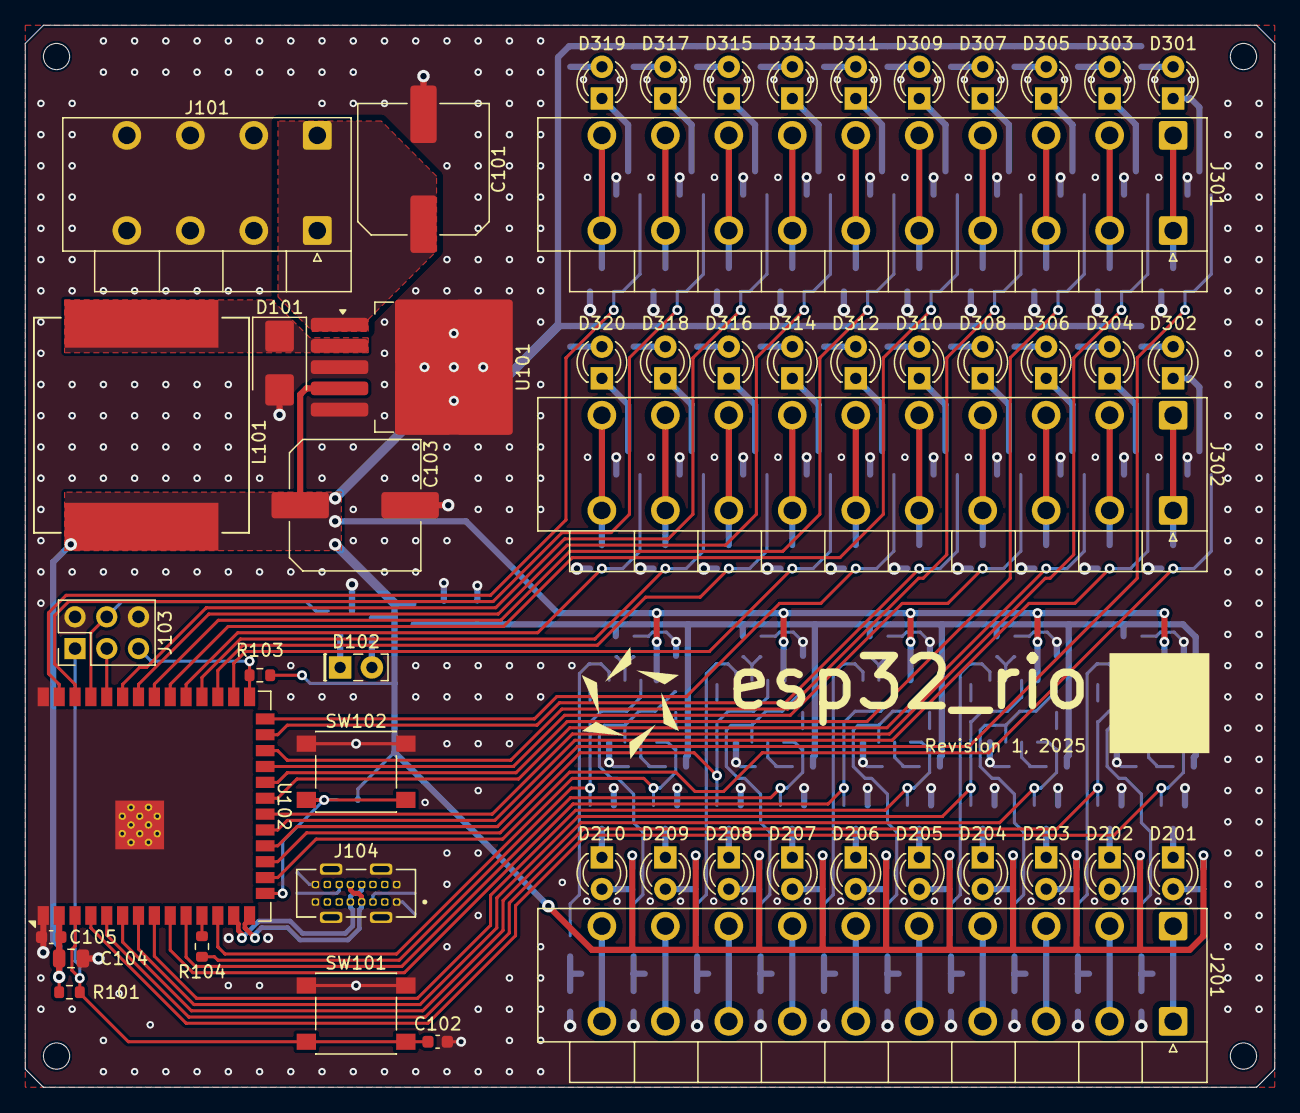
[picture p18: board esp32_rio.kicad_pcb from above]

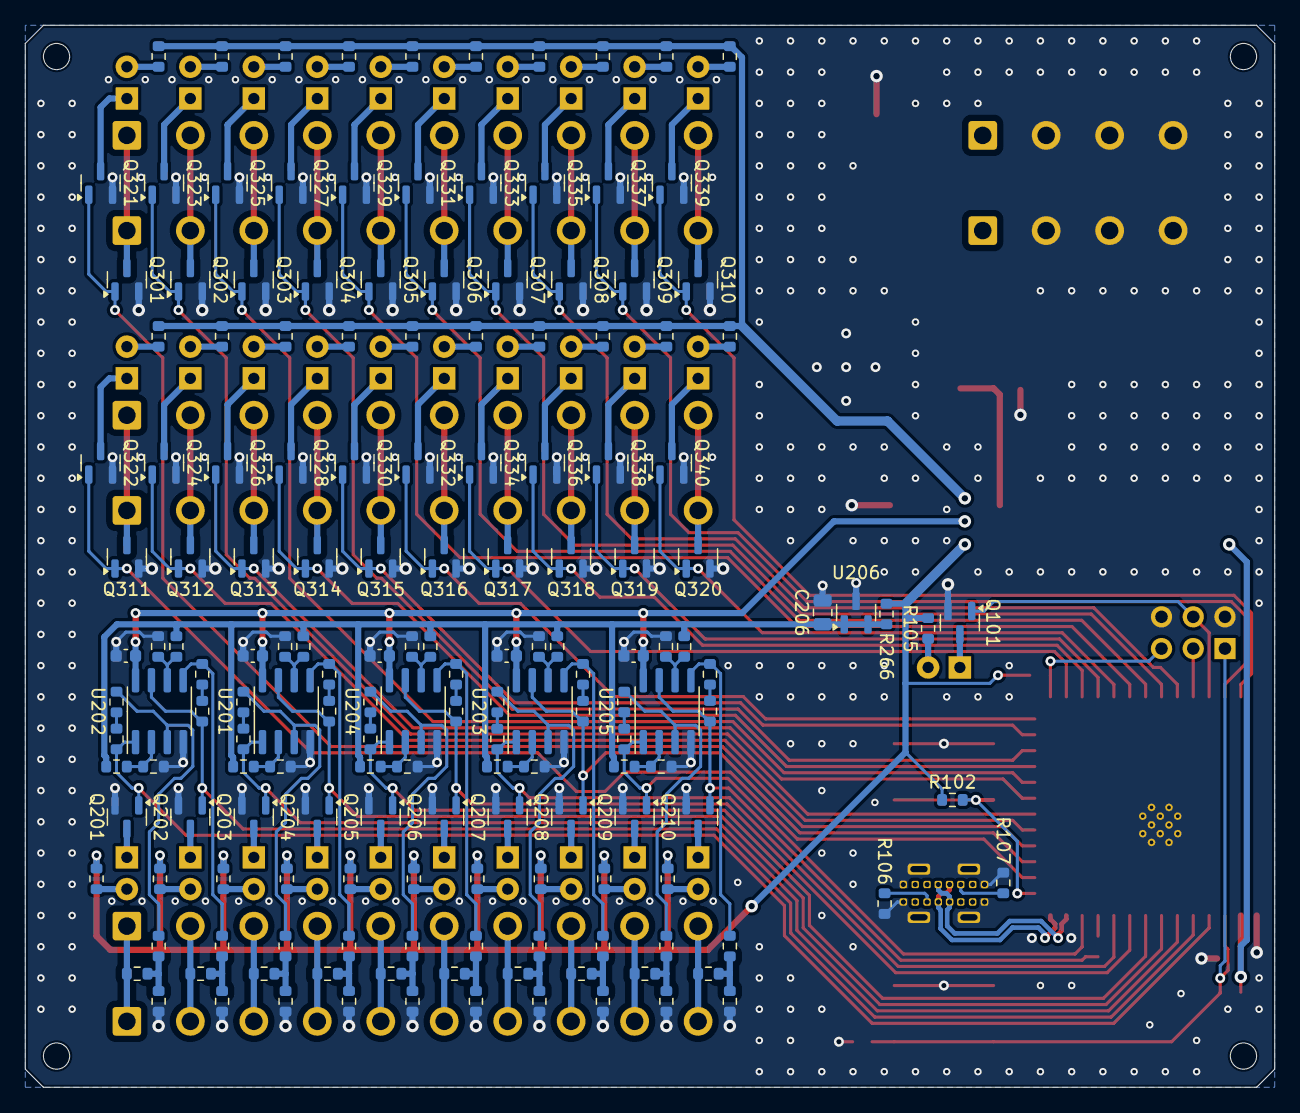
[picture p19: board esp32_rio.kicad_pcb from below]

Board: 2 copper layers, 100.0 x 85.0 mm, 223 parts (168 on the bottom side), 177 nets.

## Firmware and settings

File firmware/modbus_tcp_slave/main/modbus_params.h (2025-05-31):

/*
@file modbus_params.h
@brief Modbus parameter definitions and register mapping for the Modbus TCP Slave.

This file defines Modbus register addresses, data structures for coils and discrete inputs,
and utility macros for accessing and manipulating Modbus parameters with critical section protection.

@copyright 2025 Douglas Almeida

This file is part of the ESP32 Remote IO Modbus TCP Slave project.
It is subject to the terms of the MIT License, which can be found in the LICENSE file.

SPDX-License-Identifier: MIT
*/

#ifndef MODBUS_PARAMS_H
#define MODBUS_PARAMS_H

#define MB_REG_DISCRETE_INPUT_START 0x0000
#define MB_REG_COILS_START          0x0000

#define OE_COIL_ADDR 31 //Coil for enabling/disabling outputs

#define MB_IS_COIL_ON(address) \
    ({ \
        uint16_t addr = (address); \
        bool result = false; \
        portENTER_CRITICAL(&param_lock); \
        if (addr < 16) { \
            result = (coil_reg_params.coils_bank0 & (1U << addr)) != 0; \
        } else if (addr >= 16 && addr < 32) { \
            result = (coil_reg_params.coils_bank1 & (1U << (addr - 16))) != 0; \
        } \
        portEXIT_CRITICAL(&param_lock); \
        result; /* Return the result of the expression */ \
    })

#define MB_TURN_COIL_ON(address) \
    do { \
        uint16_t addr = (address); \
        portENTER_CRITICAL(&param_lock); \
        if (addr < 16) { \
            coil_reg_params.coils_bank0 |= (1U << addr); \
        } else if (addr >= 16 && addr < 32) { \
            coil_reg_params.coils_bank1 |= (1U << (addr - 16)); \
        } \
        portEXIT_CRITICAL(&param_lock); \
    } while(0)

#define MB_TURN_COIL_OFF(address) \
    do { \
        uint16_t addr = (address); \
        portENTER_CRITICAL(&param_lock); \
        if (addr < 16) { \
            coil_reg_params.coils_bank0 &= ~(1ULL << addr); \
        } else if (addr >= 16 && addr < 32) { \
            coil_reg_params.coils_bank1 &= ~(1ULL << (addr - 16)); \
        } \
        portEXIT_CRITICAL(&param_lock); \
    } while(0)

/*
 Modbus parameters declaring modbus address space for each modbus register type (coils, discrete inputs, holding registers, input registers)
 
 Coils bank 0:
 Address    Assignment
 0          DQ00
 1          DQ01
 2          DQ02
 3          DQ03
 4          DQ04
 5          DQ05
 6          DQ06
 7          DQ07
 8          DQ08
 9          DQ09
 10         (Reserved)
 11         (Reserved)
 12         (Reserved)
 13         (Reserved)
 14         (Reserved)
 15         (Reserved)
 
 Coils bank 1:
 Address    Assignment
 16         DQ10
 17         DQ11
 18         DQ12
 19         DQ13
 20         DQ14
 21         DQ15
 22         DQ16
 23         DQ17
 24         DQ18
 25         DQ19
 26         (Reserved)
 27         (Reserved)
 28         (Reserved)
 29         (Reserved)
 30         (Reserved)
 31         Output Enable
 
 Discrete Inputs:
 Address    Assignment
 0          DI0
 1          DI1
 2          DI2
 3          DI3
 4          DI4
 5          DI5
 6          DI6
 7          DI7
 8          DI8
 9          DI9
 10         (Reserved)
 11         (Reserved)
 12         (Reserved)
 13         (Reserved)
 14         (Reserved)
 15         (Reserved)
*/

typedef struct {
    uint16_t coils_bank0;
    uint16_t coils_bank1;
} coil_reg_params_t;

typedef struct {
    uint16_t discrete_inputs;
} discrete_reg_params_t;

#endif //MODBUS_PARAMS_H

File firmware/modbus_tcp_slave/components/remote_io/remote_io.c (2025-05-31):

/*
@file remote_io.c
@brief Implementation for the remote I/O component.

This file provides functions for configuring and managing GPIOs on the ESP32,
including digital inputs, digital outputs, a status LED, and an output enable (OE) button.
It handles GPIO interrupts, debouncing, and Morse code blinking for status indication.

@copyright 2025 Douglas Almeida

This file is part of the ESP32 Remote IO Modbus TCP Slave project.
It is subject to the terms of the MIT License, which can be found in the LICENSE file.

SPDX-License-Identifier: MIT
*/

#include "esp_log.h"
#include "esp_check.h"
#include "driver/gpio.h"
#include "freertos/FreeRTOS.h"
#include "freertos/task.h"
#include "freertos/queue.h"
#include "freertos/timers.h"

#include "remote_io.h"

#define STATUS_LED      43  //IO43 (TXD0)
#define OE_TOGGLE_BTN   3   //IO3

// Morse code timings (in milliseconds)
#define MORSE_DOT_DURATION_MS       250
#define MORSE_DASH_DURATION_MS      (3 * MORSE_DOT_DURATION_MS)
#define MORSE_ELEMENT_PAUSE_MS      MORSE_DOT_DURATION_MS
#define MORSE_LETTER_PAUSE_MS       (3 * MORSE_DOT_DURATION_MS)
#define MORSE_WORD_PAUSE_MS         (7 * MORSE_DOT_DURATION_MS)

static void io_task(void *);
static void io_isr_handler(void *);
static void debounce_timer_callback(TimerHandle_t);
static void morse_blinker_task(void *);

static const char *TAG = "ESP32_RIO_IO";

static const gpio_num_t DI[ESP32_RIO_NUM_IO_CHANNELS]   = {4, 5, 6, 7, 15, 16, 17, 9, 8, 18};
static const gpio_num_t DQ0[ESP32_RIO_NUM_IO_CHANNELS]  = {10, 12, 14, 47, 39, 40, 41, 42, 2, 1};
static const gpio_num_t DQ1[ESP32_RIO_NUM_IO_CHANNELS]  = {46, 11, 13, 21, 48, 45, 35, 36, 37, 38};

#define DEBOUNCE_TIME_MS 250
static TimerHandle_t s_debounce_timer = NULL;
static bool s_button_pressed = false;

static oe_button_toggle_cb_t s_oe_button_toggle_callback = NULL;
static di_level_change_cb_t s_di_level_change_callback = NULL;

static QueueHandle_t s_io_event_queue = NULL;
static TaskHandle_t s_io_task_handle = NULL;


/*
 Configure GPIO for esp32_rio board
*/
void esp32_rio_configure_gpio(void) {
    // Configure input for outputs enable/disable button
    gpio_config_t di_cfg = {
        .pin_bit_mask = 1ULL << OE_TOGGLE_BTN,
        .mode = GPIO_MODE_INPUT,
        .pull_up_en = GPIO_PULLUP_DISABLE,
        .pull_down_en = GPIO_PULLDOWN_DISABLE,
        .intr_type = GPIO_INTR_NEGEDGE //Interrupt on falling edge (button press)
    };
    gpio_config(&di_cfg);
    // Configure DI pins as input
    di_cfg.intr_type = GPIO_INTR_ANYEDGE; //Interrupt on change
    for (int i = 0; i < ESP32_RIO_NUM_IO_CHANNELS; ++i) {
        di_cfg.pin_bit_mask = 1ULL << DI[i];
        gpio_config(&di_cfg);
    }

    // Configure status led
    gpio_config_t out_cfg = {
        .pin_bit_mask = 1ULL << STATUS_LED,
        .mode = GPIO_MODE_OUTPUT,
        .pull_up_en = GPIO_PULLUP_DISABLE,
        .pull_down_en = GPIO_PULLDOWN_DISABLE,
        .intr_type = GPIO_INTR_DISABLE
    };
    gpio_config(&out_cfg);
    gpio_set_level(STATUS_LED, 0); //LED off, outputs disabled by default
    // Configure DQ0x, DQ1x pins as outputs
    for (int i = 0; i < ESP32_RIO_NUM_IO_CHANNELS; ++i) {
        out_cfg.pin_bit_mask = (1ULL << DQ0[i]) | (1ULL << DQ1[i]);
        gpio_config(&out_cfg);

        gpio_set_level(DQ0[i], 0);
        gpio_set_level(DQ1[i], 0);
    }
}


/*
 Initialize I/O services
*/
esp_err_t esp32_rio_io_services_init(oe_button_toggle_cb_t oe_button_toggle_callback,
                                     di_level_change_cb_t di_level_change_callback) {
    // GPIO event queue
    s_io_event_queue = xQueueCreate(10, sizeof(uint32_t)); //Hold up to 10 GPIO numbers
    if (s_io_event_queue == NULL) {
        ESP_LOGE(TAG, "Failed to create GPIO event queue.");
        return ESP_FAIL;
    }

    // Install the GPIO ISR service
    ESP_RETURN_ON_ERROR(gpio_install_isr_service(0),
                        TAG,
                        "gpio_install_isr_service fail.");
    
    // Hook the GPIO interrupt handlers
    ESP_RETURN_ON_ERROR(gpio_isr_handler_add(OE_TOGGLE_BTN, io_isr_handler, (void*)OE_TOGGLE_BTN),
                        TAG,
                        "gpio_isr_handler_add fail.");
    for (int i = 0; i < ESP32_RIO_NUM_IO_CHANNELS; ++i) {
        ESP_RETURN_ON_ERROR(gpio_isr_handler_add(DI[i], io_isr_handler, (void*)DI[i]),
                            TAG,
                            "gpio_isr_handler_add fail.");
    }
    
    // Button debounce timer
    s_debounce_timer = xTimerCreate("DebounceTimer", pdMS_TO_TICKS(DEBOUNCE_TIME_MS), pdFALSE, (void *)0, debounce_timer_callback);
    if (s_debounce_timer == NULL) {
        ESP_LOGE(TAG, "Failed to create debounce timer.");
        vQueueDelete(s_io_event_queue);
        return ESP_FAIL;
    }
    
    // Register callbacks
    s_oe_button_toggle_callback = oe_button_toggle_callback;
    s_di_level_change_callback = di_level_change_callback;

    // GPIO task
    BaseType_t ret_task_create = xTaskCreate(io_task, "io_task", 4096, NULL, 10, &s_io_task_handle);
    if (ret_task_create != pdPASS) {
        ESP_LOGE(TAG, "Failed to create io_task: %d", ret_task_create);
        vQueueDelete(s_io_event_queue);
        xTimerDelete(s_debounce_timer, 0);
        return ESP_FAIL;
    }
    
    return ESP_OK;
}


/*
 Destroy I/O services
*/
esp_err_t esp32_rio_io_services_deinit(void){
    s_oe_button_toggle_callback = NULL;
    s_di_level_change_callback = NULL;
    
    ESP_RETURN_ON_ERROR(gpio_isr_handler_remove(OE_TOGGLE_BTN),
                        TAG,
                        "gpio_isr_handler_remove fail.");
    for (int i = 0; i < ESP32_RIO_NUM_IO_CHANNELS; ++i) {
        ESP_RETURN_ON_ERROR(gpio_isr_handler_remove(DI[i]),
                            TAG,
                            "gpio_isr_handler_remove fail.");
    }
    
    gpio_uninstall_isr_service();
    
    if (s_debounce_timer != NULL) {
        if (xTimerIsTimerActive(s_debounce_timer) != pdFALSE) {
            xTimerStop(s_debounce_timer, portMAX_DELAY);
        }
        xTimerDelete(s_debounce_timer, portMAX_DELAY);
        s_debounce_timer = NULL;
    }
    
    if (s_io_task_handle != NULL) {
        vTaskDelete(s_io_task_handle);
        s_io_task_handle = NULL;
    }
    
    if (s_io_event_queue != NULL) {
        vQueueDelete(s_io_event_queue);
        s_io_event_queue = NULL;
    }
    
    return ESP_OK;
}


/*
 Query if digital input of given number is on
*/
bool esp32_rio_is_input_on(unsigned int input_number) {
    return gpio_get_level(DI[input_number]) != 0;
}


/*
 Disable all digital outputs
*/
void esp32_rio_disable_outputs(void) {
    for (int i = 0; i < ESP32_RIO_NUM_IO_CHANNELS; i++) {
        gpio_set_level(DQ0[i], 0);
        gpio_set_level(DQ1[i], 0);
    }
}


/*
 Turn status LED on/off
*/

void esp32_rio_turn_status_led_on(void) {
    gpio_set_level(STATUS_LED, 1);
}


void esp32_rio_turn_status_led_off(void) {
    gpio_set_level(STATUS_LED, 0);
}
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
